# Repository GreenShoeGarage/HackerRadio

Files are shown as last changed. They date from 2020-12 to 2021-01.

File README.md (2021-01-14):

# HackerRadio
 
NodeMCU + I2C-controlled FM Transmitter + AP Mode + TRS Electret Microphone = Remote Control Listening Device

Adafruit Stereo FM Transmitter with RDS/RBDS Breakout - Si4713
https://www.adafruit.com/product/1958

You must also download this tool to the Arduino IDE: https://github.com/esp8266/arduino-esp8266fs-plugin  
This will allow you to upload the .HTML, and .CSS files  

You will also need these two libraries:  
https://github.com/me-no-dev/ESPAsyncTCP  
https://github.com/me-no-dev/ESPAsyncWebServer  

1. Solder length of wire for antenna
2. Wire up Si4713 breakout board to NodeMCU. Audio device must be transmitting at line level, mic level audio sources will not work.

| Node |  Si4713 |
| --- | --- |
| 3V | VIN |
| GND  | GND |
| D1 | SDA |
| D2 | SCL |
| D6 | RST |

3.  Connect TRS electret mic to Si4714 TRS jack
4.  Upload firmware
5.  Connect to "hackerradio" AP broadcast by NodeMCU
6.  Open browser, navigate to 192.168.4.1
7.  Enter a frequency and click submit  (For example 102.35MHz should be entered as 10235)
8.  Tune FM radio to same frequency
9.  Talk and listen

Example of the HTTP POST request:
http://192.168.4.1/changefrequency?newfrequency=10230

## Using with a NodeMCU

- You must edit the Adafruit_Si4713.cpp file to work with NodeMCU
- Add a new line to: bool Adafruit_Si4713::begin(uint8_t addr, TwoWire *theWire)  

...  
_wire = theWire;  
_wire->pins(4,5);  //ADD THIS LINE ONLY WHEN USING A NodeMCU <===================  
_wire->begin();  
...  

BOM  
https://partsbox.com/mbparks/project/22hpb7c3a4jxg8dhe0753b87zm/bom

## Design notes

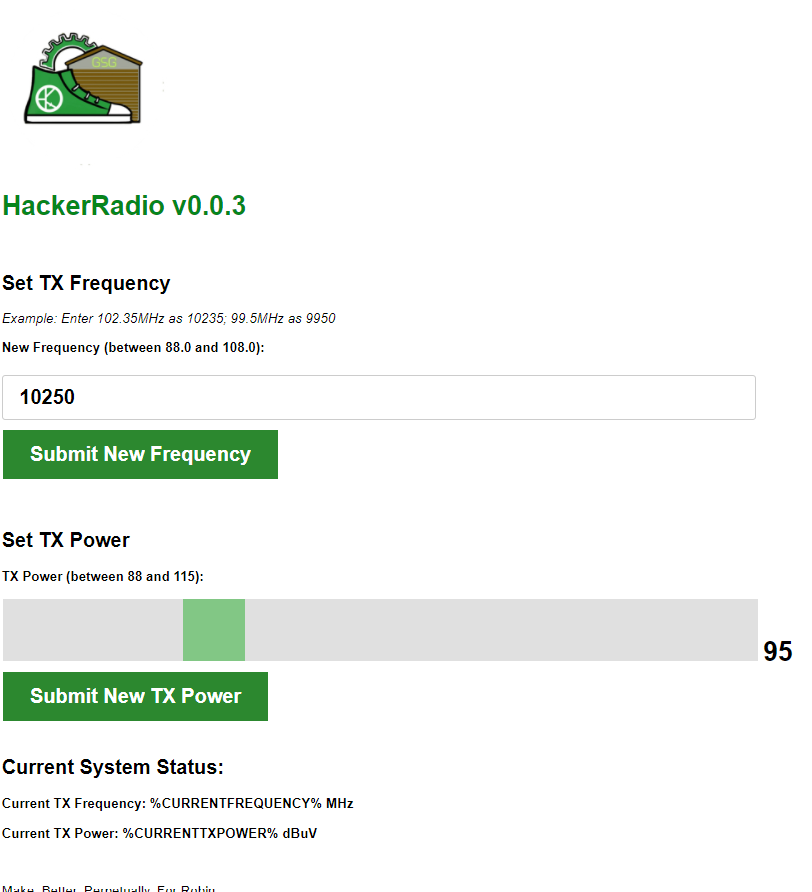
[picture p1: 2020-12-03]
Documentation/Images/hackerRadio003_GUI.png

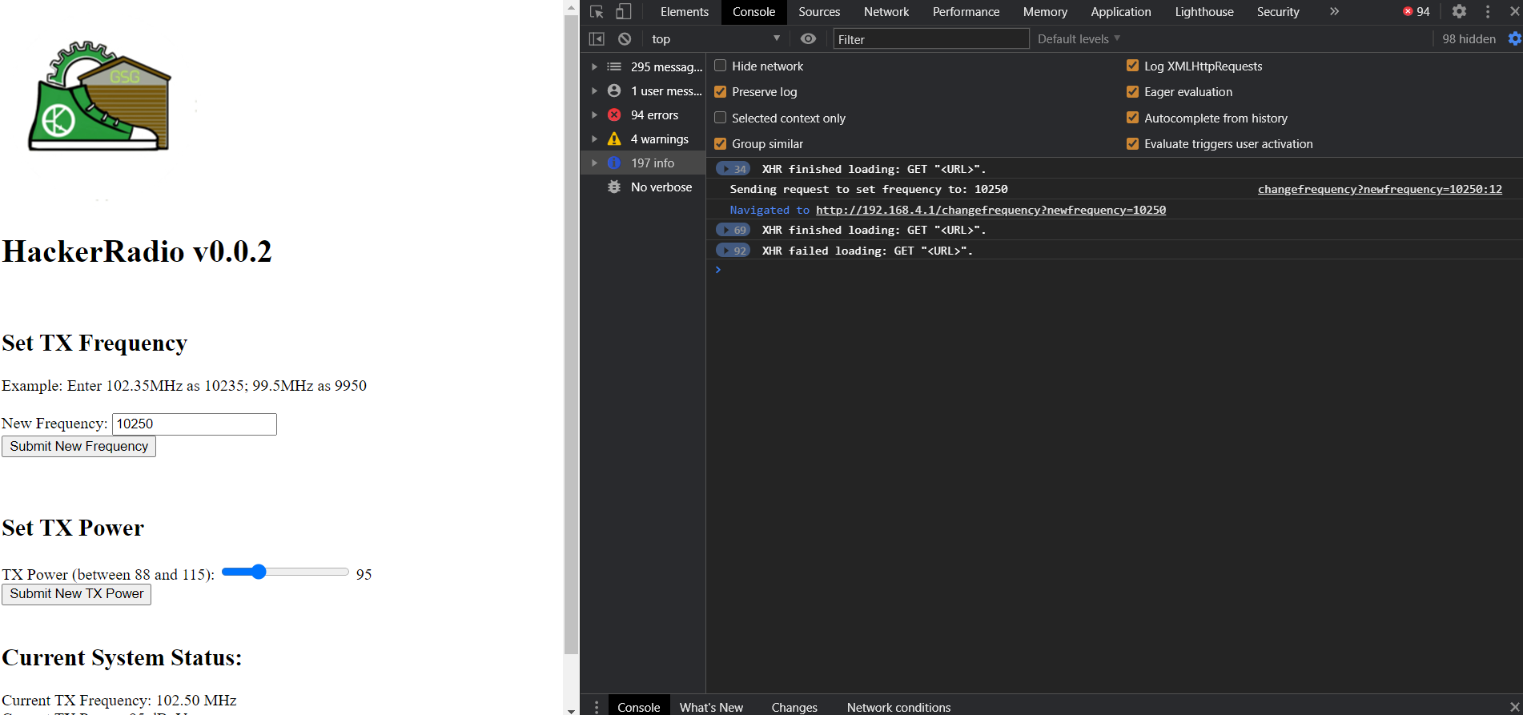
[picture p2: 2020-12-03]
Documentation/Images/hackerRadio002_GUI.png

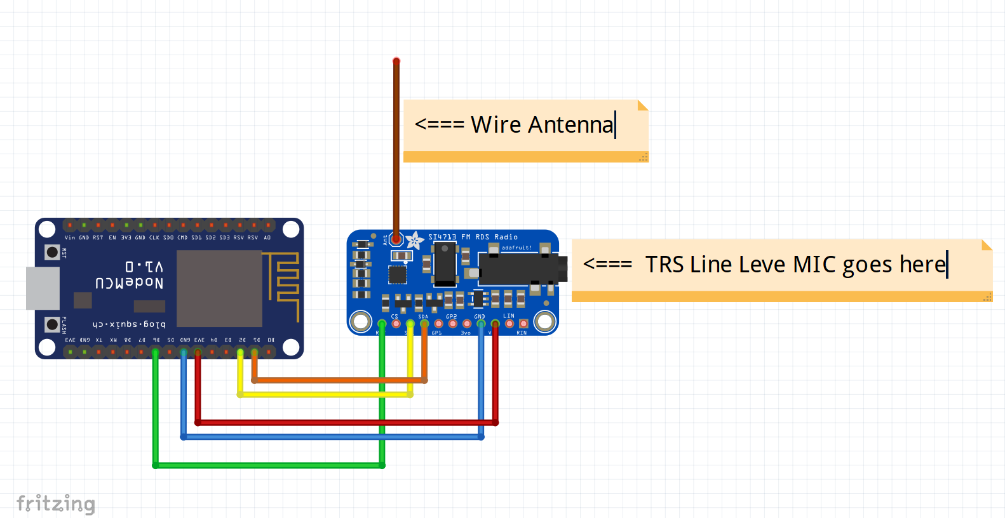
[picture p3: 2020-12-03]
Documentation/Images/physical_layout_fritzing.png

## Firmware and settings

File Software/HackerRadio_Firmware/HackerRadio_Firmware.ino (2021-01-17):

//External Libraries
#include <ESP8266WiFi.h>
#include <ESPAsyncTCP.h>
#include <ESPAsyncWebServer.h>
#include <FS.h>              // Include the SPIFFS library
#include <Adafruit_Si4713.h> //must edit Adafruit_Si4713.cpp if using NodeMCU. Must edit the begin() function to change the I2C SDA and SCL pins    _wire->pins(4,5);
#include "secrets.h"

// #DEFINE Definitions
#define RESETPIN 12
#define BAUDRATE 115200
#define DEFAULT_TXPOWER 95 //MIN 88-115 MAX
#define DEFAULT_FREQ 10230 //MIN 8800-10800 MAX
#define TCP_PORT 80


// Control debugging via serial comms
#define DEBUG

#ifdef DEBUG
#define DEBUG_PRINTLN(x) Serial.println(x)
#define DEBUG_PRINT(x) Serial.print(x)
#define DEBUG_PRINTHEX(x, HEX) Serial.print(x, HEX)
#else
#define DEBUG_PRINTLN(x)
#define DEBUG_PRINT(x)
#define DEBUG_PRINTHEX(x, HEX)
#endif



//Initialize devices
Adafruit_Si4713 radio = Adafruit_Si4713(RESETPIN);

AsyncWebServer server(TCP_PORT);


//Declare variables

unsigned int FMSTATION = DEFAULT_FREQ; // 10230 == 102.30 MHz
unsigned int TXPOWER = DEFAULT_TXPOWER;

String hr_version = "v0.0.3";

bool isRadioConnected = false;

////////////////////////////////////////////////////////////////////////////////////
void printRadioInfo()
{
  if (isRadioConnected)
  {
    radio.readTuneStatus();
    DEBUG_PRINT("Current TX Frequency: ");
    printFrequency(radio.currFreq);
    DEBUG_PRINT("\tCurrent ASQ: 0x");
    DEBUG_PRINTHEX(radio.currASQ, HEX);
    DEBUG_PRINT("\tCurrent InLevel:");
    DEBUG_PRINT(radio.currInLevel);
    DEBUG_PRINT("\tTX Power:");
    DEBUG_PRINTLN(TXPOWER);
  }
  else
  {
    printRadioErrorMessage();
  }
}

////////////////////////////////////////////////////////////////////////////
void setup()
{
  initSerial();
  initWifiAP();
  initServer();
  initSPIFFS();
  initFmRadio();
  DEBUG_PRINTLN(F("\n\nWaiting for clients to connect..."));
}

////////////////////////////////////////////////////////////////////////////
void loop()
{
}

//////////////////////////////////////////////////////////////////////////
void initSerial()
{
  Serial.begin(BAUDRATE);
  delay(10);
  DEBUG_PRINT(F("\n\nWelcome to Hacker Radio "));
  DEBUG_PRINTLN(hr_version);
  pinMode(LED_BUILTIN, OUTPUT);
  digitalWrite(LED_BUILTIN, LOW);
}

///////////////////////////////////////////////////////////////////////////
void initWifiAP()
{
  DEBUG_PRINTLN(F("Establishing WiFi AP..."));
  WiFi.mode(WIFI_AP);
  WiFi.softAP(ssid, password); // Start the access point
  DEBUG_PRINT("Access Point \"");
  DEBUG_PRINT(ssid);
  DEBUG_PRINTLN("\" started");
  DEBUG_PRINT("IP address:\t");
  DEBUG_PRINTLN(WiFi.softAPIP()); // Send the IP address of the ESP8266 to the computer
  DEBUG_PRINTLN(F("WiFi AP established."));
}

///////////////////////////////////////////////////////////////////////////////////
void initServer()
{
  DEBUG_PRINTLN(F("Starting server..."));
  server.serveStatic("/images/gsg.jpg", SPIFFS, "/images/gsg.jpg");

  server.onNotFound([](AsyncWebServerRequest *request) {
    request->send(404);
  });

  server.on("/", HTTP_ANY, [](AsyncWebServerRequest *request) {
    request->send(SPIFFS, "/index.html");
    DEBUG_PRINTLN(F("\n### Client connected."));
  });

  server.on("/index", HTTP_ANY, [](AsyncWebServerRequest *request) {
    request->send(SPIFFS, "/index.html");
    DEBUG_PRINTLN(F("\n### Client connected."));
  });

  server.on("/style.css", HTTP_ANY, [](AsyncWebServerRequest *request) {
    request->send(SPIFFS, "/style.css");
  });

  server.on("/getcurrentfrequency", HTTP_ANY, [](AsyncWebServerRequest *request) {
    String s = String(FMSTATION / 100);
    s += ".";
    s += String(FMSTATION % 100);
    request->send(200, "plain/text", s);
  });

  server.on("/getcurrenttxpower", HTTP_ANY, [](AsyncWebServerRequest *request) {
    String s = String(TXPOWER);
    request->send(200, "plain/text", s);
  });

  server.on("/changefrequency", HTTP_ANY, [](AsyncWebServerRequest *request) {
    if (request->hasParam("newfrequency"), true)
    {
      AsyncWebParameter *param = request->getParam("newfrequency", false);
      String param_string = param->value();
      int NEW_FMSTATION = param_string.toInt();

      DEBUG_PRINT(F("\n### Received request to change frequency to: "));
      printFrequency(NEW_FMSTATION);
      DEBUG_PRINTLN("");

      if (NEW_FMSTATION >= 8800 && NEW_FMSTATION <= 10800)
      {
        FMSTATION = NEW_FMSTATION;
        radio.tuneFM(FMSTATION);
      }
      else
      {
        DEBUG_PRINTLN(F("!!! ERROR: Invalid frequency selected. Must be between 88 and 108 MHz."));
      }

      request->send(SPIFFS, "/index.html");
      printRadioInfo();
    }
  });

  server.on("/changetxpower", HTTP_ANY, [](AsyncWebServerRequest *request) {
    if (request->hasParam("newtxpower"), true)
    {
      AsyncWebParameter *param = request->getParam("newtxpower", false);
      String param_string = param->value();
      unsigned int NEW_TXPOWER = param_string.toInt();

      DEBUG_PRINT(F("\n### Received request to change TX power to: "));
      DEBUG_PRINT(NEW_TXPOWER);
      DEBUG_PRINTLN(F("dBuV"));
      if (NEW_TXPOWER >= 88 && NEW_TXPOWER <= 115)
      {
        TXPOWER = NEW_TXPOWER;
        radio.setTXpower(TXPOWER);
      }
      else
      {
        DEBUG_PRINTLN(F("!!! ERROR: TX power is limited to between 88 and 115 dBuV"));
      }

      request->send(SPIFFS, "/index.html");

      printRadioInfo();
    }
  });

  server.begin();
  DEBUG_PRINTLN(F("Server is running."));
}

///////////////////////////////////////////////////////////////////////////////////////
void initFmRadio()
{
  DEBUG_PRINT(F("\n\nConnecting to FM radio..."));
  if (!radio.begin())
  { // begin with address 0x63 (CS high default)
    DEBUG_PRINTLN(F("FAILED! Couldn't find radio!"));
    //while (1);
  }
  else
  {
    DEBUG_PRINTLN("connected.");
    isRadioConnected = true;
  }

  if (isRadioConnected)
  {
    // Uncomment to scan power of entire range from 87.5 to 108.0 MHz
    /*
    for (uint16_t f  = 8750; f<10800; f+=10) {
    radio.readTuneMeasure(f);
    DEBUG_PRINT("Measuring "); DEBUG_PRINT(f); DEBUG_PRINT("...");
    radio.readTuneStatus();
    DEBUG_PRINTLN(radio.currNoiseLevel);
    }
  */
    radio.setGPIOctrl((1 << 2) || (1 << 1));
    radio.setGPIO((1 << 2) || (1 << 1));
    DEBUG_PRINT(F("Tuning to: "));
    printFrequency(FMSTATION);
    radio.tuneFM(FMSTATION);
    DEBUG_PRINT(F("\nSetting TX power to: "));
    DEBUG_PRINT(TXPOWER);
    DEBUG_PRINTLN(F(" dBuV"));
    radio.setTXpower(TXPOWER); // dBuV, 88-115 max
    printRadioInfo();

    // begin the RDS/RDBS transmission
    radio.beginRDS();
    radio.setRDSstation("HackerRadio");
    radio.setRDSbuffer("HackerRadio FTW!");
    DEBUG_PRINTLN(F("RDS on!"));
    DEBUG_PRINTLN(F("Radio setup complete."));
  }
  else
  {
    printRadioErrorMessage();
  }
}

/////////////////////////////////////////////////////
void initSPIFFS()
{
  if (!SPIFFS.begin())
  {
    Serial.println("An Error has occurred while mounting SPIFFS");
    return;
  }
}

/////////////////////////////////////////////////////
void printFrequency(int frequency)
{
  DEBUG_PRINT(frequency / 100);
  DEBUG_PRINT(".");
  DEBUG_PRINT(frequency % 100);
  DEBUG_PRINT(" MHz");
}

/////////////////////////////////////////////////////
void printRadioErrorMessage()
{
  DEBUG_PRINTLN(F("Radio disconnected. Check wiring and then reboot system."));
}

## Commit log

2020-11-26 fix URL for changing freequency
    http://192.168.4.1/changefrequency?frequency=10230
    [HackerRadio_Firmware.ino]
2020-11-29 Serial.print can now be toggled on/off with #define DEBUG
2020-12-03 added hardware documentation
    [hackerRadio.fzz]
2020-12-03 added 404 error handler
    [HackerRadio_Firmware.ino]
2020-12-03 added slider to control TX power
2020-12-03 broke out WiFIAP and Server init into separate functions
    [HackerRadio_Firmware.ino]
2020-12-03 stylized buttons and slider with css
2020-12-03 stylize buttons and slider with css
2021-01-14 add support for arduino-lint-action
2021-01-14 Create main.yml for arduino-lint-action
    arduino-lint-action
    https://github.com/marketplace/actions/arduino-arduino-lint-action?version=v1.0.0
